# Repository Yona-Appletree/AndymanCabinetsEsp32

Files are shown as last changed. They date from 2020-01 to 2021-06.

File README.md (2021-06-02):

# Cabinet Controller

## IP Addresses
North Pixlite: 192.168.8.20
South Pixlite: 192.168.8.21

Router: 192.168.8.1
South Bridge: 192.168.8.138

## Prerequisties

    brew install platformio

## USB

Upload & Monitor:

    pio run -e usb -t upload -t monitor
    
Monitor:

    pio run -e usb -t monitor
    
## OTA

PlatformIO OTA Info: https://docs.platformio.org/en/latest/platforms/espressif32.html#over-the-air-ota-update

Upload:

    pio run -e ota -t upload
    
Upload and Monitor (with USB connected):

    pio run -e ota -t upload && pio run -e usb -t monitor

## Notes

PlatformIO Documentation: https://docs.platformio.org/en/latest/quickstart.html

Install Library: pio lib install "FastLED"
wESP Documentation: https://wesp32.com/software/

## TODO

- [ ] Refactor programs into class
- [ ] Support preview of programs
- [ ] Indicate selector positions

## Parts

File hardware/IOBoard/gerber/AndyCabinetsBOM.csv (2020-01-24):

Id | Designator | Package | Quantity | Designation | Supplier and ref
1 | SW1 | RotaryEncoder_Alps_EC12E-SMDSwitch_Vertical_H20mm_CircularMountingHoles | 1 | Color_Encoder
2 | J1 | PinSocket_2x10_P2.54mm_Vertical_SMD_Mirror | 1 | wESP Connector
3 | JP1 | SolderJumper-2_P1.3mm_Open_TrianglePad1.0x1.5mm | 1 | wESP Power Jumper
4 | EXT2,EXT1 | PinHeader_1x10_P2.54mm_Vertical_SMD_Pin1Left | 2 | NS(HN1x10)
5 | D2,D16,D15,D1,D14,D13,D12,D11,D10,D9,D8,D7,D6,D5,D4,D3 | LED_SK6812MINI_PLCC4_3.5x3.5mm_P1.75mm | 16 | WS2812B
6 | R14,R13,R12,R11,R10,R9,R8,R7,R6,R5,R4,R3,R2,R1 | R_0402_1005Metric | 14 | 10K
7 | C12,C9,C13,C11,C6,C5 | C_0402_1005Metric | 6 | 0.1uF
8 | C10,C4,C3,C2,C1 | C_0805_2012Metric | 5 | 1uF
9 | RV2 | Potentiometer_TT_P0915N_Flush | 1 | SpeedPot
10 | RV1 | Potentiometer_TT_P0915N_Flush | 1 | BrightPot
11 | U1 | SOIC-14_3.9x8.7mm_P1.27mm | 1 | 74HC14
12 | C8,C7 | C_0402_1005Metric | 2 | 0.01uF
13 | SW2 | RotaryEncoder_Alps_EC12E-Switch_Vertical_H20mm_CircularMountingHoles | 1 | Mode_Encoder

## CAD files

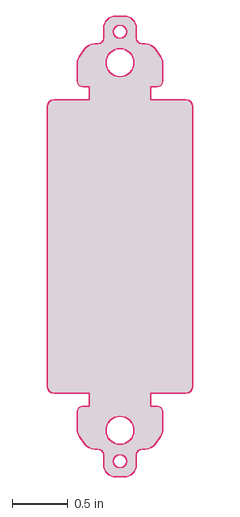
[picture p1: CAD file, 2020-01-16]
hardware/FaceplateBoard/FaceplateOutline.dxf
1.30 x 4.12 in

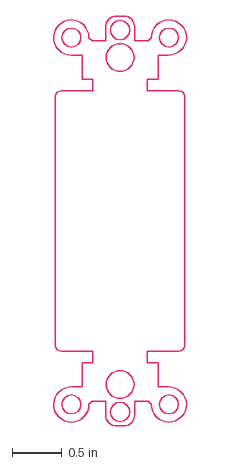
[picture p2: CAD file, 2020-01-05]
hardware/FaceplateBoardFront/FaceplateOutline.dxf
1.34 x 4.12 in

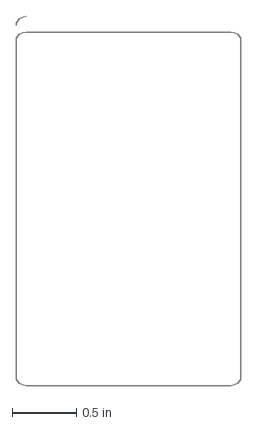
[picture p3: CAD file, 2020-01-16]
hardware/IOBoard/InsideBoardSize.dxf
1.75 x 2.88 in

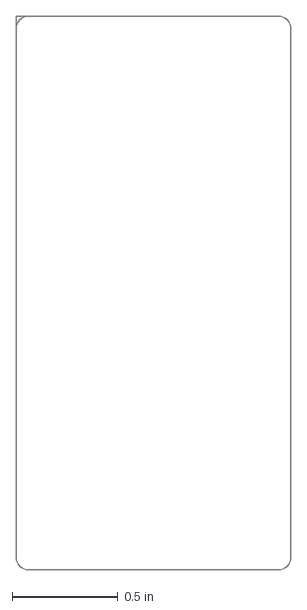
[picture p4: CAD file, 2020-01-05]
hardware/IOBoard/AndyCabinetsOutline2.dxf
1.30 x 2.62 in

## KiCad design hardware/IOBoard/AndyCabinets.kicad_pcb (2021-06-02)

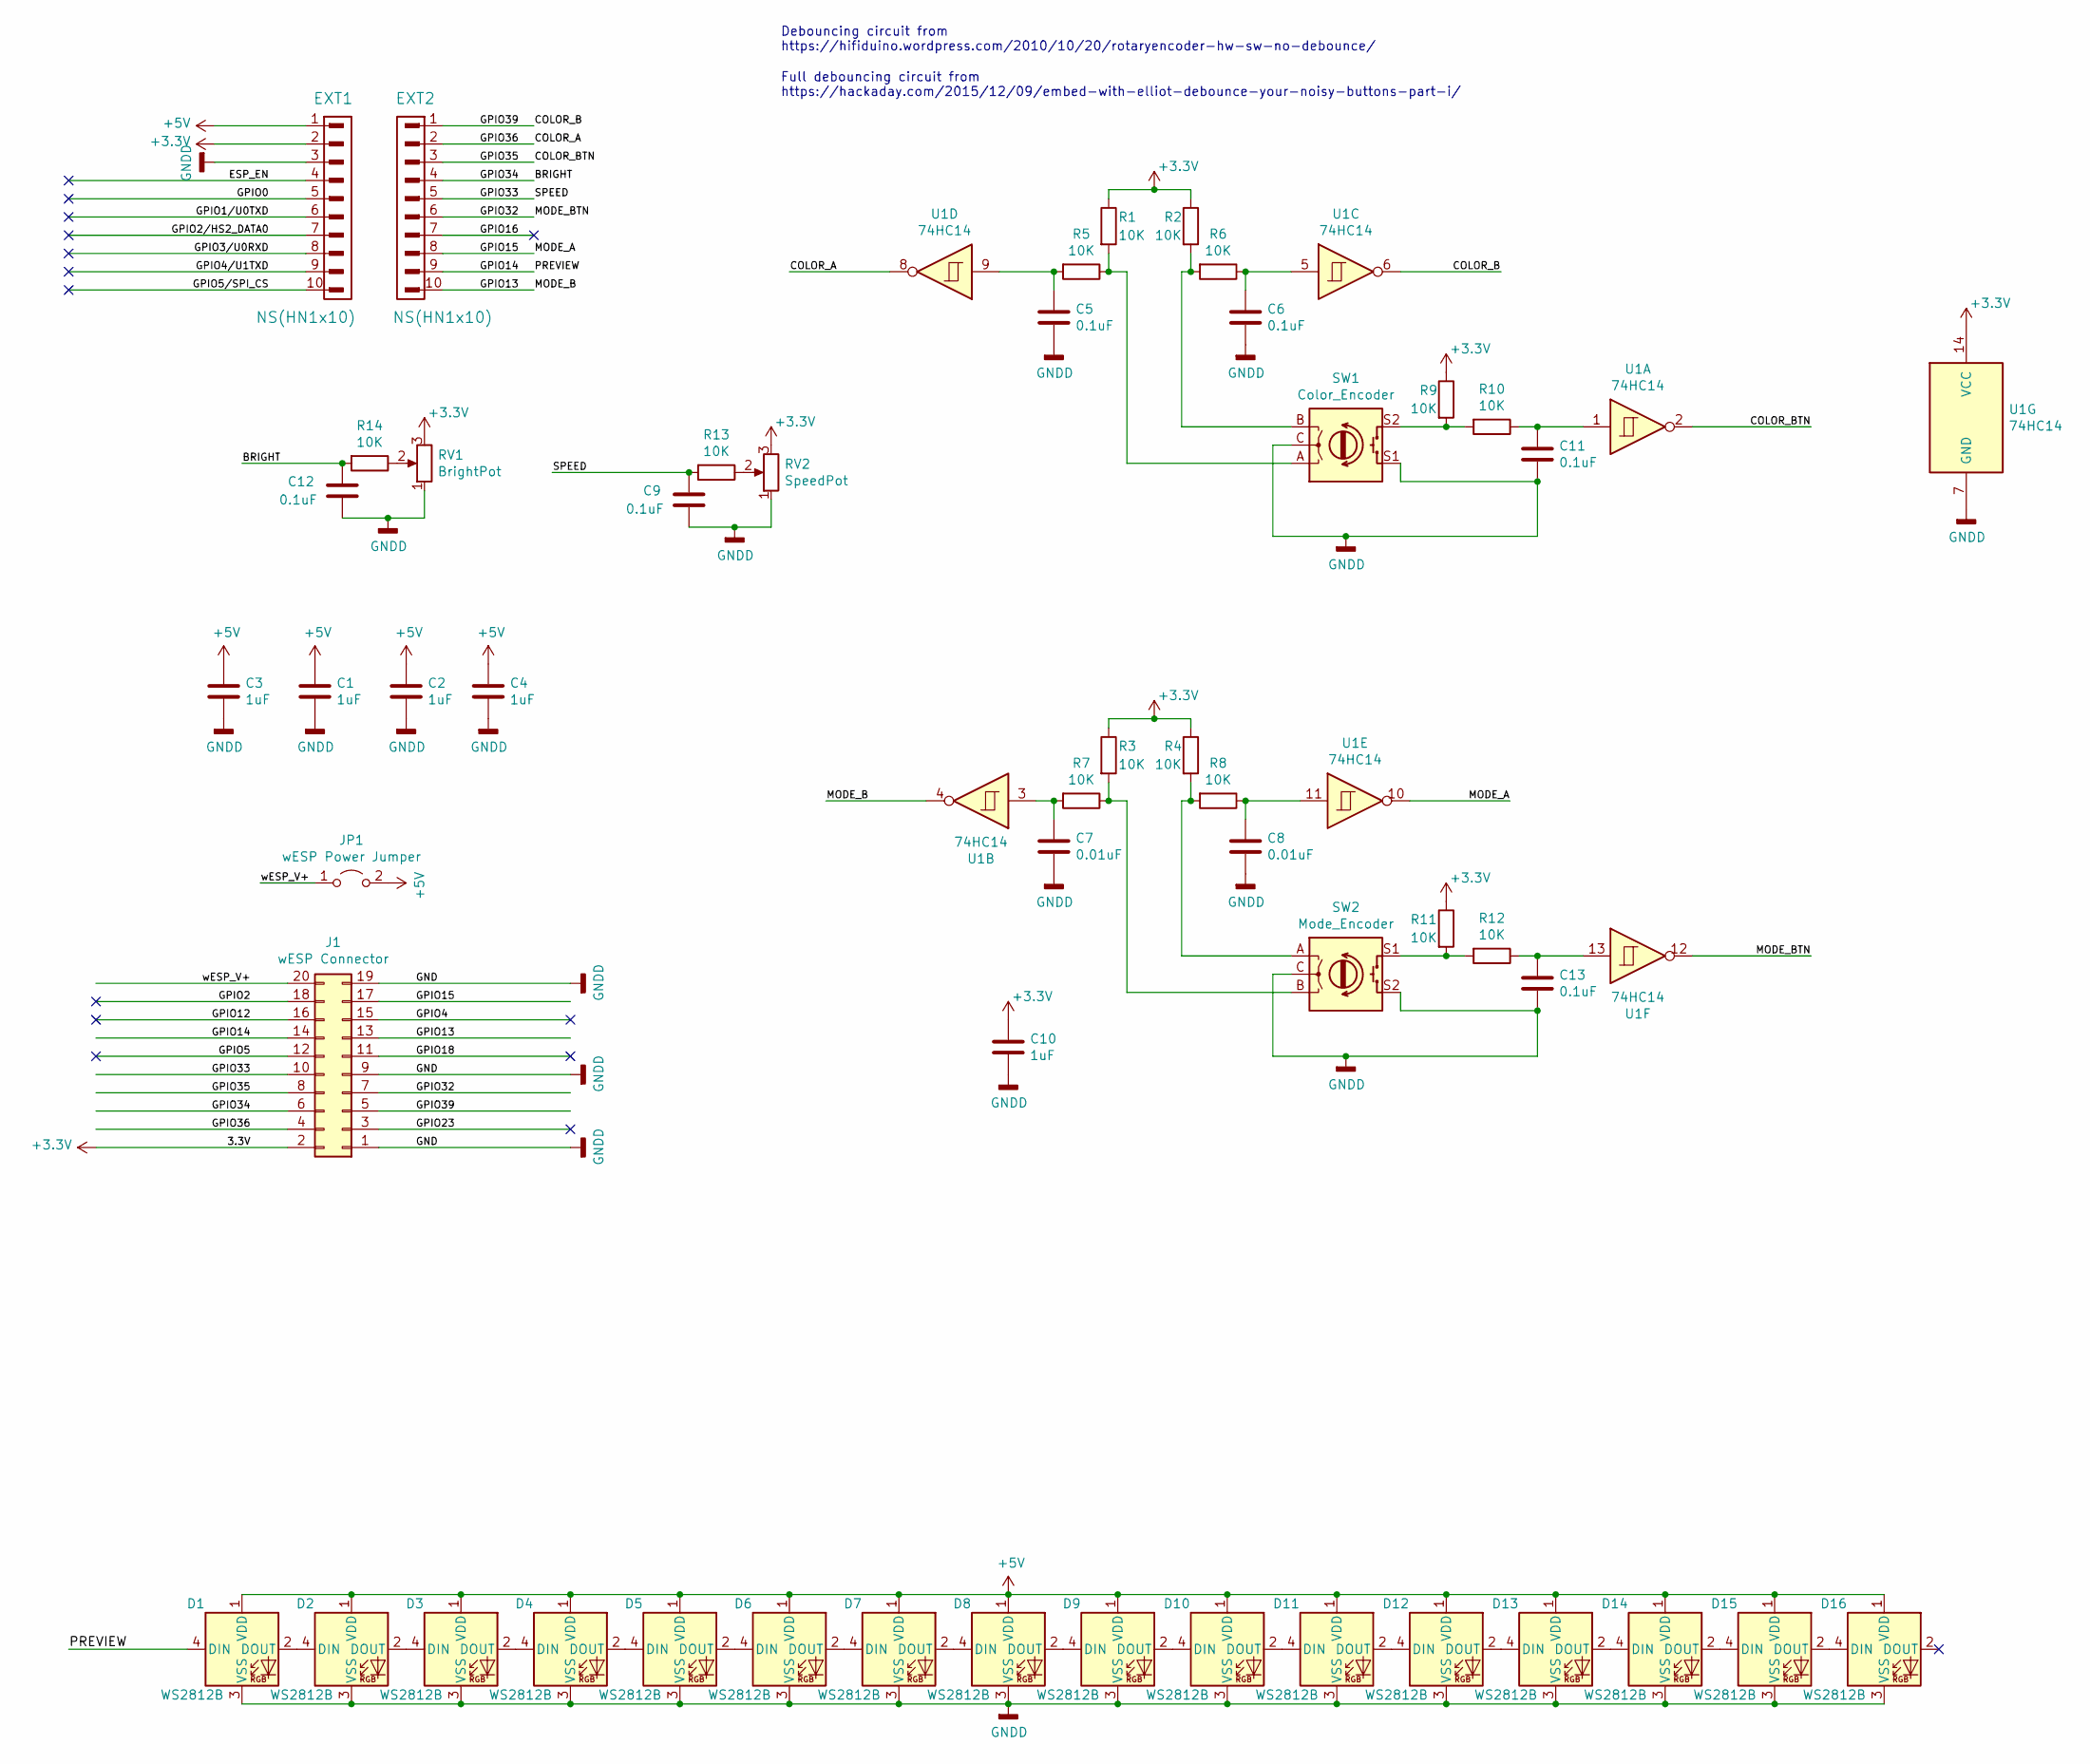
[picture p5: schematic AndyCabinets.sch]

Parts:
C1, C2, C3, C4, C10: 1uF; C_0805_2012Metric
C5, C6, C9, C11, C12, C13: 0.1uF; C_0402_1005Metric
C7, C8: 0.01uF; C_0402_1005Metric
D1, D2, D3, D4, D5, D6, D7, D8, D9, D10, D11, D12, D13, D14, D15, D16: WS2812B; LED_SK6812MINI_PLCC4_3.5x3.5mm_P1.75mm
EXT1, EXT2: NS(HN1x10); PinHeader_1x10_P2.54mm_Vertical_SMD_Pin1Left
J1: wESP Connector; PinSocket_2x10_P2.54mm_Vertical_SMD_Mirror
JP1: wESP Power Jumper; SolderJumper-2_P1.3mm_Open_TrianglePad1.0x1.5mm
R1, R2, R3, R4, R5, R6, R7, R8, R9, R10, R11, R12, R13, R14: 10K; R_0402_1005Metric
RV1: BrightPot; Potentiometer_TT_P0915N_Flush
RV2: SpeedPot; Potentiometer_TT_P0915N_Flush
SW1: Color_Encoder; RotaryEncoder_Alps_EC12E-SMDSwitch_Vertical_H20mm_CircularM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
SW2: Mode_Encoder; RotaryEncoder_Alps_EC12E-Switch_Vertical_H20mm_CircularMoun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
U1: 74HC14; SOIC-14_3.9x8.7mm_P1.27mm

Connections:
+3V3: C10.1, EXT1.2, J1.2, R1.1, R2.1, R3.1, R4.1, R9.1, R11.1, RV1.3, RV2.3, U1.14 (VCC)
+5V: C1.1, C2.1, C3.1, C4.1, D1.1 (VDD), D2.1 (VDD), D3.1 (VDD), D4.1 (VDD), D5.1 (VDD), D6.1 (VDD), D7.1 (VDD), D8.1 (VDD), D9.1 (VDD), D10.1 (VDD), D11.1 (VDD), D12.1 (VDD), D13.1 (VDD), D14.1 (VDD), D15.1 (VDD), D16.1 (VDD), EXT1.1, JP1.2 (B)
/BRIGHT: C12.1, EXT2.4, J1.6, R14.2
/COLOR_A: EXT2.2, J1.4, U1.8
/COLOR_B: EXT2.1, J1.5, U1.6
/COLOR_BTN: EXT2.3, J1.8, U1.2
/ESP_EN: EXT1.4
/GPIO0: EXT1.5
/GPIO1/U0TXD: EXT1.6
/GPIO2: J1.18
/GPIO2/HS2_DATA0: EXT1.7
/GPIO3/U0RXD: EXT1.8
/GPIO4: J1.15
/GPIO4/U1TXD: EXT1.9
/GPIO5: J1.12
/GPIO5/SPI_CS: EXT1.10
/GPIO12: J1.16
/GPIO13: EXT2.10, J1.13, U1.4
/GPIO14: D1.4 (DIN), EXT2.9, J1.14
/GPIO15: EXT2.8, J1.17, U1.10
/GPIO16: EXT2.7
/GPIO18: J1.11
/GPIO23: J1.3
/GPIO32: EXT2.6, J1.7, U1.12
/GPIO33: C9.1, EXT2.5, J1.10, R13.2
/wESP_V+: J1.20, JP1.1 (A)
GNDD: C1.2, C2.2, C3.2, C4.2, C5.2, C6.2, C7.2, C8.2, C9.2, C10.2, C11.2, C12.2, C13.2, D1.3 (VSS), D2.3 (VSS), D3.3 (VSS), D4.3 (VSS), D5.3 (VSS), D6.3 (VSS), D7.3 (VSS), D8.3 (VSS), D9.3 (VSS), D10.3 (VSS), D11.3 (VSS), D12.3 (VSS), D13.3 (VSS), D14.3 (VSS), D15.3 (VSS), D16.3 (VSS), EXT1.3, J1.1, J1.9, J1.19, RV1.1, RV2.1, SW1.C, SW1.S1, SW2.C, SW2.S2, U1.7 (GND)
unnamed: C5.1, R5.2, U1.9
unnamed: C6.1, R6.1, U1.5
unnamed: C7.1, R7.2, U1.3
unnamed: C8.1, R8.1, U1.11
unnamed: C11.1, R10.1, U1.1
unnamed: C13.1, R12.1, U1.13
unnamed: D1.2 (DOUT), D2.4 (DIN)
unnamed: D2.2 (DOUT), D3.4 (DIN)
unnamed: D3.2 (DOUT), D4.4 (DIN)
unnamed: D4.2 (DOUT), D5.4 (DIN)
unnamed: D5.2 (DOUT), D6.4 (DIN)
unnamed: D6.2 (DOUT), D7.4 (DIN)
unnamed: D7.2 (DOUT), D8.4 (DIN)
unnamed: D8.2 (DOUT), D9.4 (DIN)
unnamed: D10.2 (DOUT), D11.4 (DIN)
unnamed: D9.2 (DOUT), D10.4 (DIN)
unnamed: D11.2 (DOUT), D12.4 (DIN)
unnamed: D12.2 (DOUT), D13.4 (DIN)
unnamed: D13.2 (DOUT), D14.4 (DIN)
unnamed: D14.2 (DOUT), D15.4 (DIN)
unnamed: D15.2 (DOUT), D16.4 (DIN)
unnamed: R1.2, R5.1, SW1.A
unnamed: R2.2, R6.2, SW1.B
unnamed: R3.2, R7.1, SW2.B
unnamed: R4.2, R8.2, SW2.A
unnamed: R9.2, R10.2, SW1.S2
unnamed: R11.2, R12.2, SW2.S1
unnamed: R13.1, RV2.2
unnamed: R14.1, RV1.2

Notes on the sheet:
Debouncing circuit from https://hifiduino.wordpress.com/2010/10/20/rotaryencoder-hw-sw-no-debounce/
Full debouncing circuit from https://hackaday.com/2015/12/09/embed-with-elliot-debounce-your-noisy-buttons-part-i/

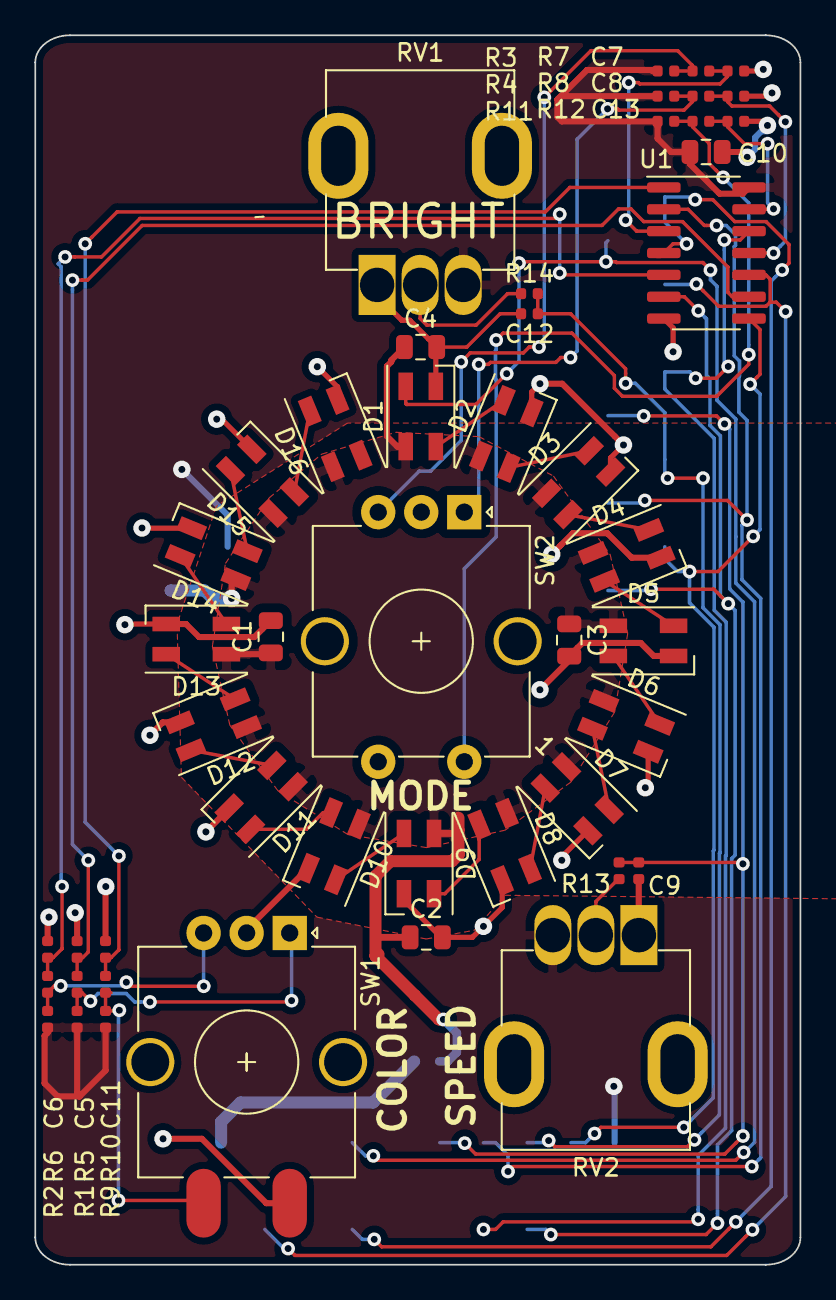
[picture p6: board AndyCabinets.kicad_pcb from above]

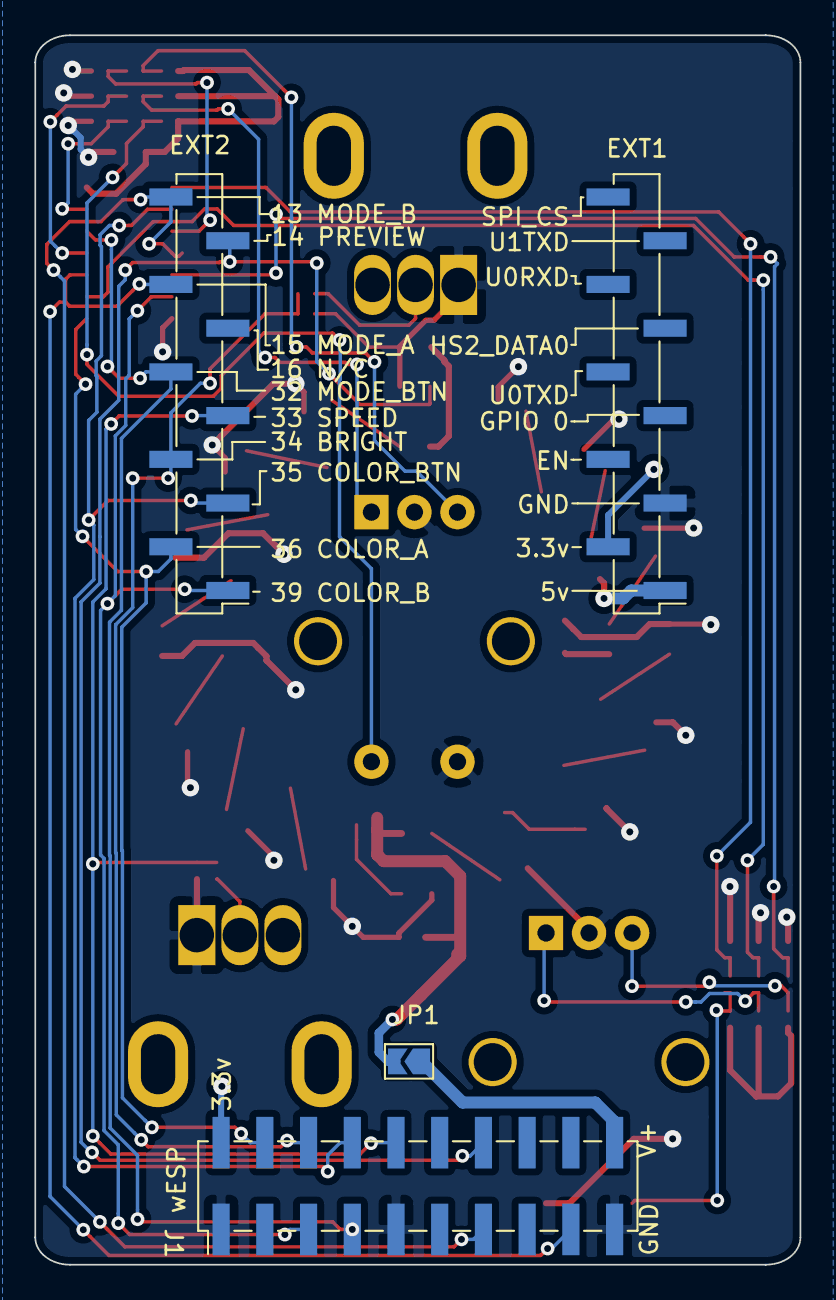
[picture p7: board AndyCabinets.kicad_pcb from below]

Board: 2 copper layers, 44.4 x 71.4 mm, 52 parts (4 on the bottom side), 42 nets.

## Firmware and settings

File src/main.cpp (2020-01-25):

#include "network.h"
#include "ui.h"

#include "renderer.h"

void core2loop(void * data);
TaskHandle_t renderTask;

volatile bool rendererStarted = false;

const auto frameMs = 1000 / 30;

void setup()
{
	Serial.begin(115200);

	uiSetup();
	colorSetup();
	networkSetup();

	xTaskCreatePinnedToCore(
		core2loop, /* Function to implement the task */
		"Render", /* Name of the task */
		10000,  /* Stack size in words */
		NULL,  /* Task input parameter */
		0,  /* Priority of the task */
		&renderTask,  /* Task handle. */
		0  /* Core where the task should run */
	);
}


void loop()
{
	auto start = millis();

	uiLoop();
	colorLoop();
	networkLoop();

	if (rendererStarted) {
		rendererSend();
	}

	auto duration = millis() - start;

	if (duration < frameMs) {
		FastLED.delay(frameMs - duration);
	}
}

#pragma clang diagnostic push
#pragma clang diagnostic ignored "-Wmissing-noreturn"
void core2loop(void * data) {
	// Wait for network
	while (! g_ethConnected) {
		delay(100);
	}

	rendererSetup();

	rendererStarted = true;

	while (true) {
		auto start = millis();

		rendererLoop();

		auto duration = millis() - start;

		//Serial.printf("render ms: %d\n", (int) duration);

		if (duration < frameMs) {
			delay(frameMs - duration);
		}
	}
}
#pragma clang diagnostic pop

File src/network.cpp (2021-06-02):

//
// Created by Yona Appletree on 12/30/19.
//

#define ARDUHAL_LOG_LEVEL ARDUHAL_LOG_LEVEL_INFO

#include "network.h"
#include <ETH.h>
#include <WebServer.h>
#include <ESPmDNS.h>
#include <ArduinoOTA.h>

#define HOSTNAME "andycabinets"

void handleNetworkEvent(WiFiEvent_t event);
bool g_ethConnected = false;

// Web server
WebServer server(80);

// HTTP handlers
void handleRoot() {
	server.send(200, "text/plain", "Hello from Andycabinets\n");
}

void handleNotFound() {
	server.send(404, "text/plain", String("No ") + server.uri() + " here!\n");
}

void networkSetup(){
	// Listen to events
	WiFi.onEvent(handleNetworkEvent);

	// No WiFi until we get the analog pins on ADC1
	// See table here: https://desire.giesecke.tk/index.php/2018/01/30/adc2-channel-cannot-be-used-when-wifi-is-in-use/
	// And thread here: https://github.com/espressif/arduino-esp32/issues/102

//	if (WiFi.config(
//		IPAddress(192, 168, 1, 210),
//		IPAddress(192, 168, 1, 1),
//		IPAddress(255, 255, 255, 0),
//		IPAddress(8, 8, 4, 4),
//		IPAddress(8, 8, 8, 8)
//	)) {
//		Serial.println("Configured WiFi for static IP");
//	} else {
//		Serial.println("Failed to configure WiFi for static IP");
//	}
//
//	WiFi.begin("AndyCabinetsMain", "playingwithlight");

	Serial.println("ETH Starting...");

	// Start the ethernet
	ETH.begin();
//	ETH.config(
//		IPAddress(192, 168, 8, 5),
//		IPAddress(192, 168, 8, 1),
//		IPAddress(255, 255, 255, 0),
//		IPAddress(192, 168, 8, 1),
//		IPAddress(192, 168, 8, 1)
//	);

	// Bind HTTP handler
	server.on("/", handleRoot);
	server.onNotFound(handleNotFound);

	// Start the Ethernet web server
	server.begin();

	// Setup OTA updates
	ArduinoOTA
		.setMdnsEnabled(true)
		.setHostname(HOSTNAME)
		.onStart([]() {
			String type = (ArduinoOTA.getCommand() == U_FLASH)
				? "sketch"
				: "filesystem";

			// NOTE: if updating SPIFFS this would be the place to unmount SPIFFS using SPIFFS.end()
			Serial.println("OTA: Start updating " + type);
		})
		.onEnd([]() {
			Serial.println("\nOTA: End");
		})
		.onProgress([](unsigned int progress, unsigned int total) {
			Serial.printf("OTA: Progress: %u%%\r", (progress / (total / 100)));
		})
		.onError([](ota_error_t error) {
			Serial.printf("OTA: Error[%u]: ", error);
			if (error == OTA_AUTH_ERROR) Serial.println("OTA: Auth Failed");
			else if (error == OTA_BEGIN_ERROR) Serial.println("OTA: Begin Failed");
			else if (error == OTA_CONNECT_ERROR) Serial.println("OTA: Connect Failed");
			else if (error == OTA_RECEIVE_ERROR) Serial.println("OTA: Receive Failed");
			else if (error == OTA_END_ERROR) Serial.println("OTA: End Failed");
		})
		.begin();

	// Add service to MDNS-SD
	MDNS.addService("http", "tcp", 80);
}

void networkLoop(){
	server.handleClient();
	ArduinoOTA.handle();
}

void handleNetworkEvent(WiFiEvent_t event) {
	switch (event) {
		case SYSTEM_EVENT_ETH_START:
			Serial.println("ETH Started");
			//set eth hostname here
			ETH.setHostname(HOSTNAME);
			break;

		case SYSTEM_EVENT_ETH_CONNECTED:
			Serial.println("ETH Connected");
			break;

		case SYSTEM_EVENT_ETH_GOT_IP:
			Serial.print("ETH MAC: ");
			Serial.print(ETH.macAddress());
			Serial.print(", IPv4: ");
			Serial.print(ETH.localIP());
			if (ETH.fullDuplex()) {
				Serial.print(", FULL_DUPLEX");
			}
			Serial.print(", ");
			Serial.print(ETH.linkSpeed());
			Serial.println("Mbps");
			g_ethConnected = true;

			break;

		case SYSTEM_EVENT_ETH_DISCONNECTED:
			Serial.println("ETH Disconnected");
			g_ethConnected = false;
			break;

		case SYSTEM_EVENT_ETH_STOP:
			Serial.println("ETH Stopped");
			g_ethConnected = false;
			break;

		default:
			break;
	}
}

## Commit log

2019-12-31 Updated notes, added hardware
    [AndyCabinets.kicad_pcb, AndyCabinets.sch, AndyCabinetsBOM.csv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]
2020-01-02 Updated schematic to use 3.3v for analog inputs
    [AndyCabinets.sch]
2020-01-02 Minor schematic cleanup
    [AndyCabinets.kicad_pcb, AndyCabinets.sch]
2020-01-02 Hardware: Rotary Encoder Play
    [AndyCabinets.sch]
2020-01-05 Rotary Encoder Board Work
    [AndyCabinets.kicad_pcb, AndyCabinets.sch, AndyCabinetsBOM.csv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]
2020-01-05 Added faceplate boards
    [AndyCabinets.kicad_pcb, AndyCabinets.sch, FaceplateBoard.kicad_pcb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]
2020-01-05 Pre-larger inside board relayout
    [AndyCabinets.kicad_pcb, InsideBoardSize.dxf]
2020-01-16 After PCB v2
    [AndyCabinets.kicad_pcb, AndyCabinets.sch, AndyCabinetsBOM.csv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]
2020-01-22 Initial working remote version; some minor PCB changes
    [AndyCabinets.kicad_pcb, AndyCabinets.sch]
2020-01-23 Rev 3 PCB
    [AndyCabinets.kicad_pcb, AndyCabinets.sch]
2020-01-24 Refactored visualizations and improved preview; Moved networking to main core; Wifi support added but disabled on current hardware;
2020-01-24 Hardware v3-beta1 (not run yet)
    [AndyCabinets-B_Cu.gbr, AndyCabinets-B_Mask.gbr, AndyCabinets-B_Paste.gbr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]
2020-01-25 More UI improvements, reverted speed changes due to jitter
    [main.cpp, ui.cpp, visualizations.cpp]
2021-06-02 Hardware pre change to SMD2020
    [AndyCabinets.kicad_pcb, AndyCabinets.sch]
